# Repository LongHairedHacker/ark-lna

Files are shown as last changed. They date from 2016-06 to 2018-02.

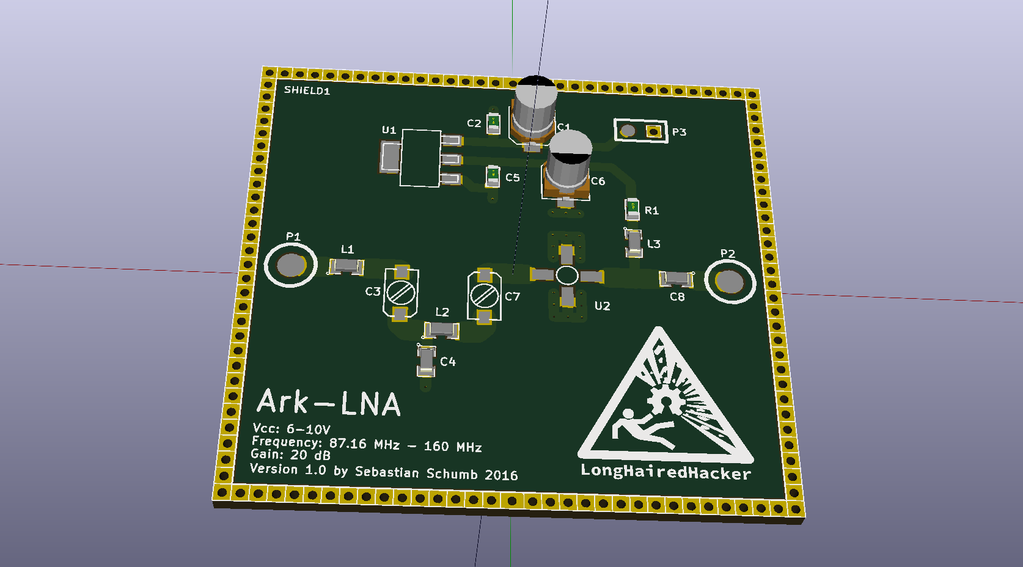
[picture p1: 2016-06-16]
plot/ark-lna.png

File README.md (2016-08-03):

ARK-LNA
=======
A low noise amplifier based on the MAR-6 or MAR-8.
It was designed with NOAA weather satellites in mind,
but might be useful for other VHF transmissions as well.

* Supply voltage: 6-10V
* Minimal center frequency: 87.16 MHz
* Maximal center frequency: 160 MHz
* Bandwidth: To be determined
* Gain: 20 dB

Parts
=====

| Count | Part				| Manufacturer Part	|
|---|---|---|
|  2 | Trimmer 3-10pf	| TZC3R100A110R00 	|
|  2 | Inductor 330nH	| MLF2012DR33JTD25	|
|  1 | 33pF 0805 | CL21C330JBANNNC |
|  1 | Inductor 10uH		| LBR2012T100K |
|  1 | 91 Ohm 0603 | RC0603JR-0791RL |
|  1 | 100pF 0805 | C0805C101J5GACTU  |
|  2 | 10uF | UUT1V100MCL1GS |
|  2 | 100nF 0603 | CL03A104KQ3NNNH |
|  1 | Voltage regulator | LM1117-5 |
|  1 | amplifier | MAR-6 / MAR-8 |
|  1 | case | TEKO 371 |

Notes
=====
* Case inner dimensions: 46.5mm x 50.5mm
* MAR-6+
    * Datasheet: http://194.75.38.69/pdfs/MAR-6+.pdf
    * Layout suggestions: https://www.minicircuits.com/pcb/98-pl262.pdf

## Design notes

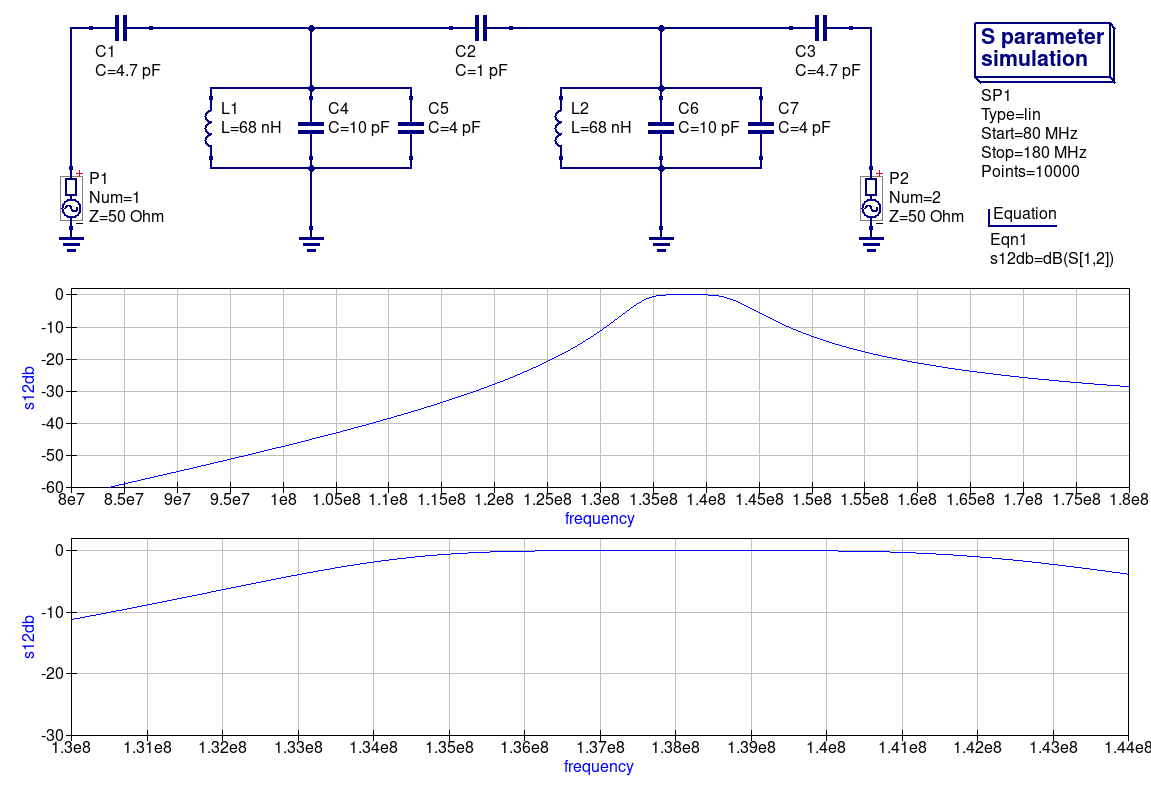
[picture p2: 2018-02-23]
plot/filter.png

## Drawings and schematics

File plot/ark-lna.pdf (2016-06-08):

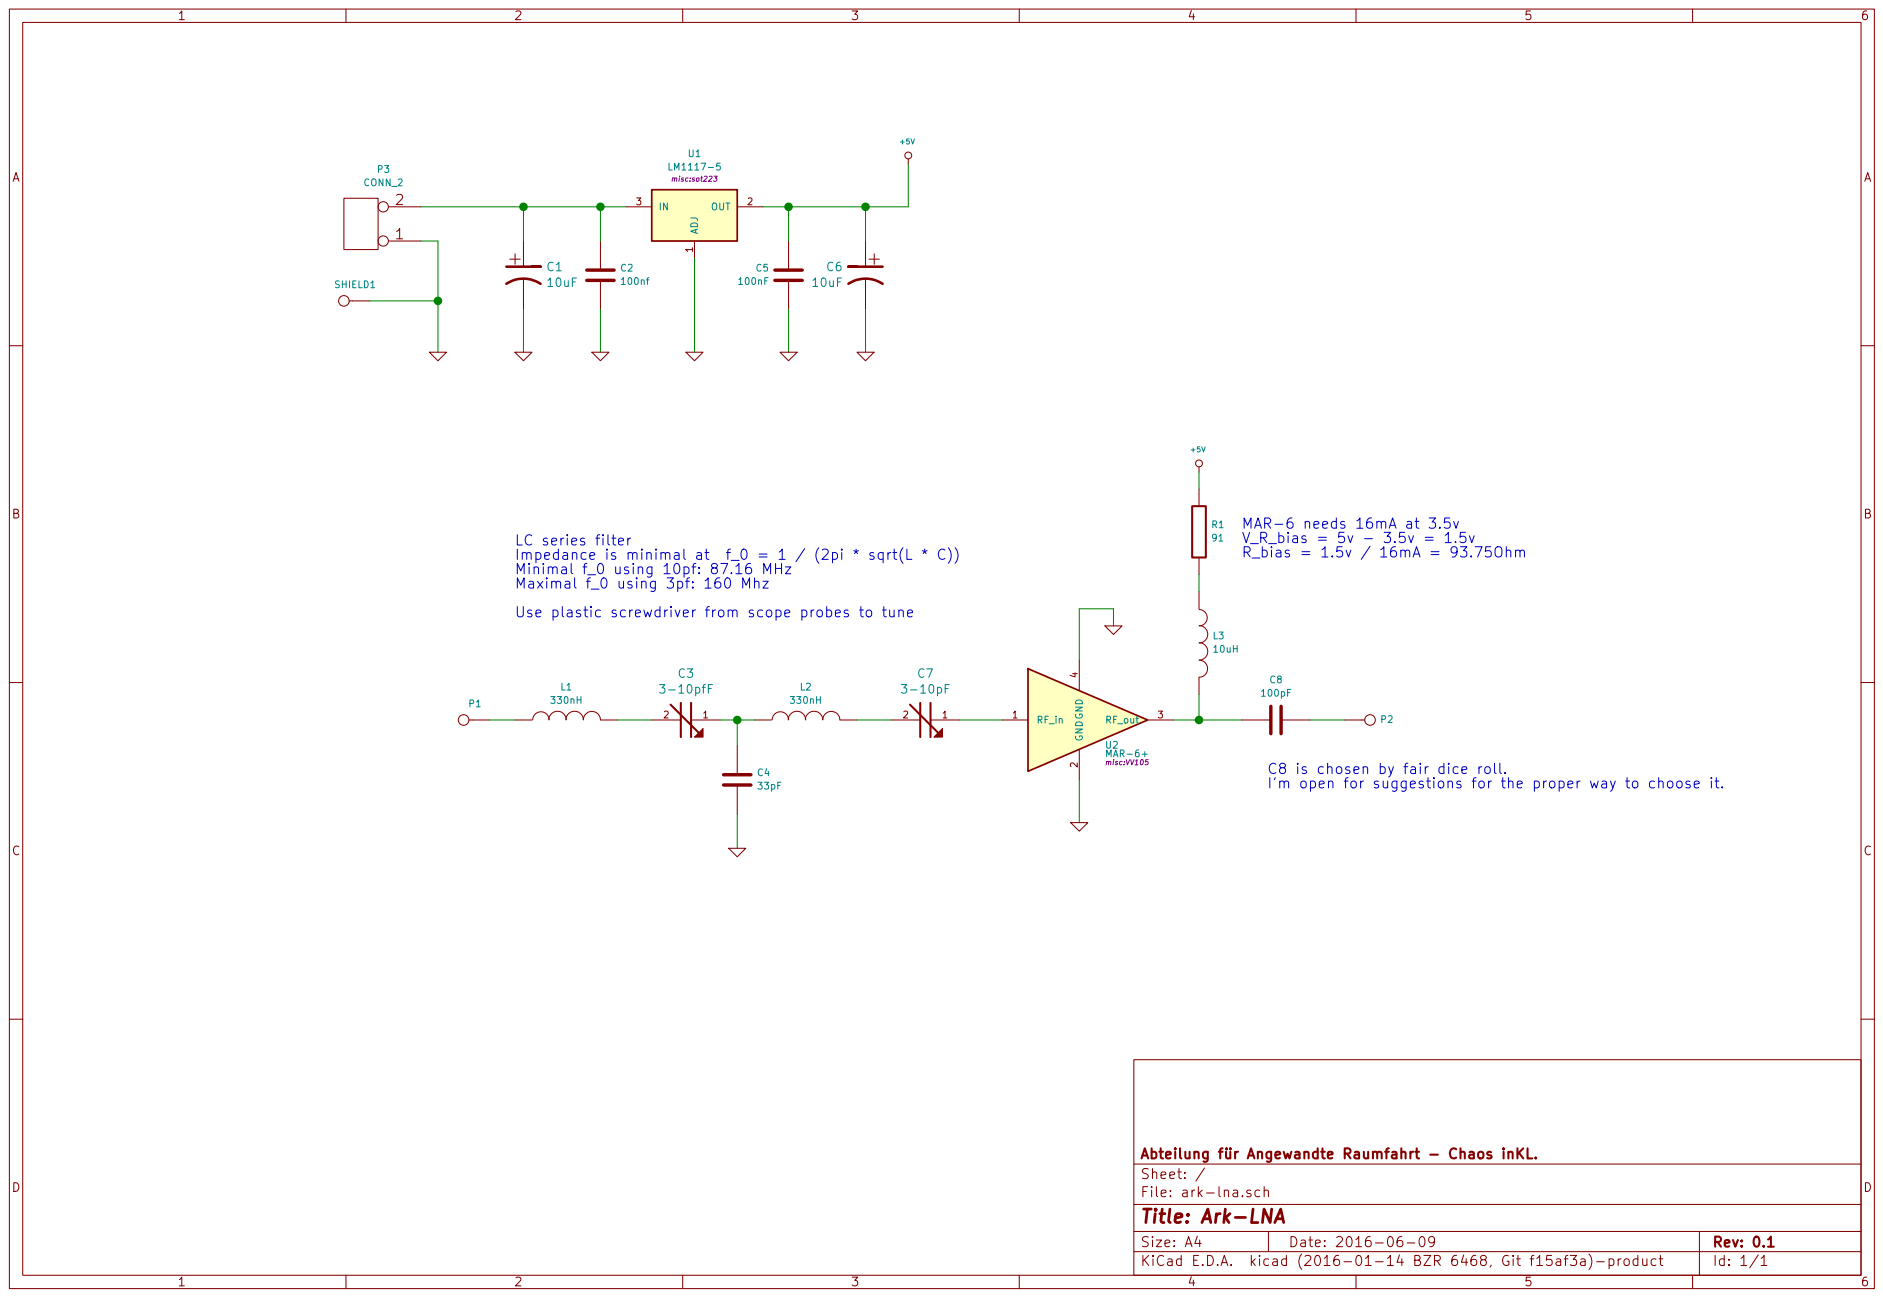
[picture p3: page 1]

I'm open for suggestions for the proper way to choose it. 1

100pF LC series filter
Impedance is minimal at f_0 = 1 / (2pi * sqrt(L * C))
Minimal f_0 using 10pf: 87.16 MHz
Maximal f_0 using 3pf: 160 Mhz

File: ark-lna.sch Sheet: / Abteilung für Angewandte Raumfahrt - Chaos inKL.

Id: 1/1 Title: Ark-LNA

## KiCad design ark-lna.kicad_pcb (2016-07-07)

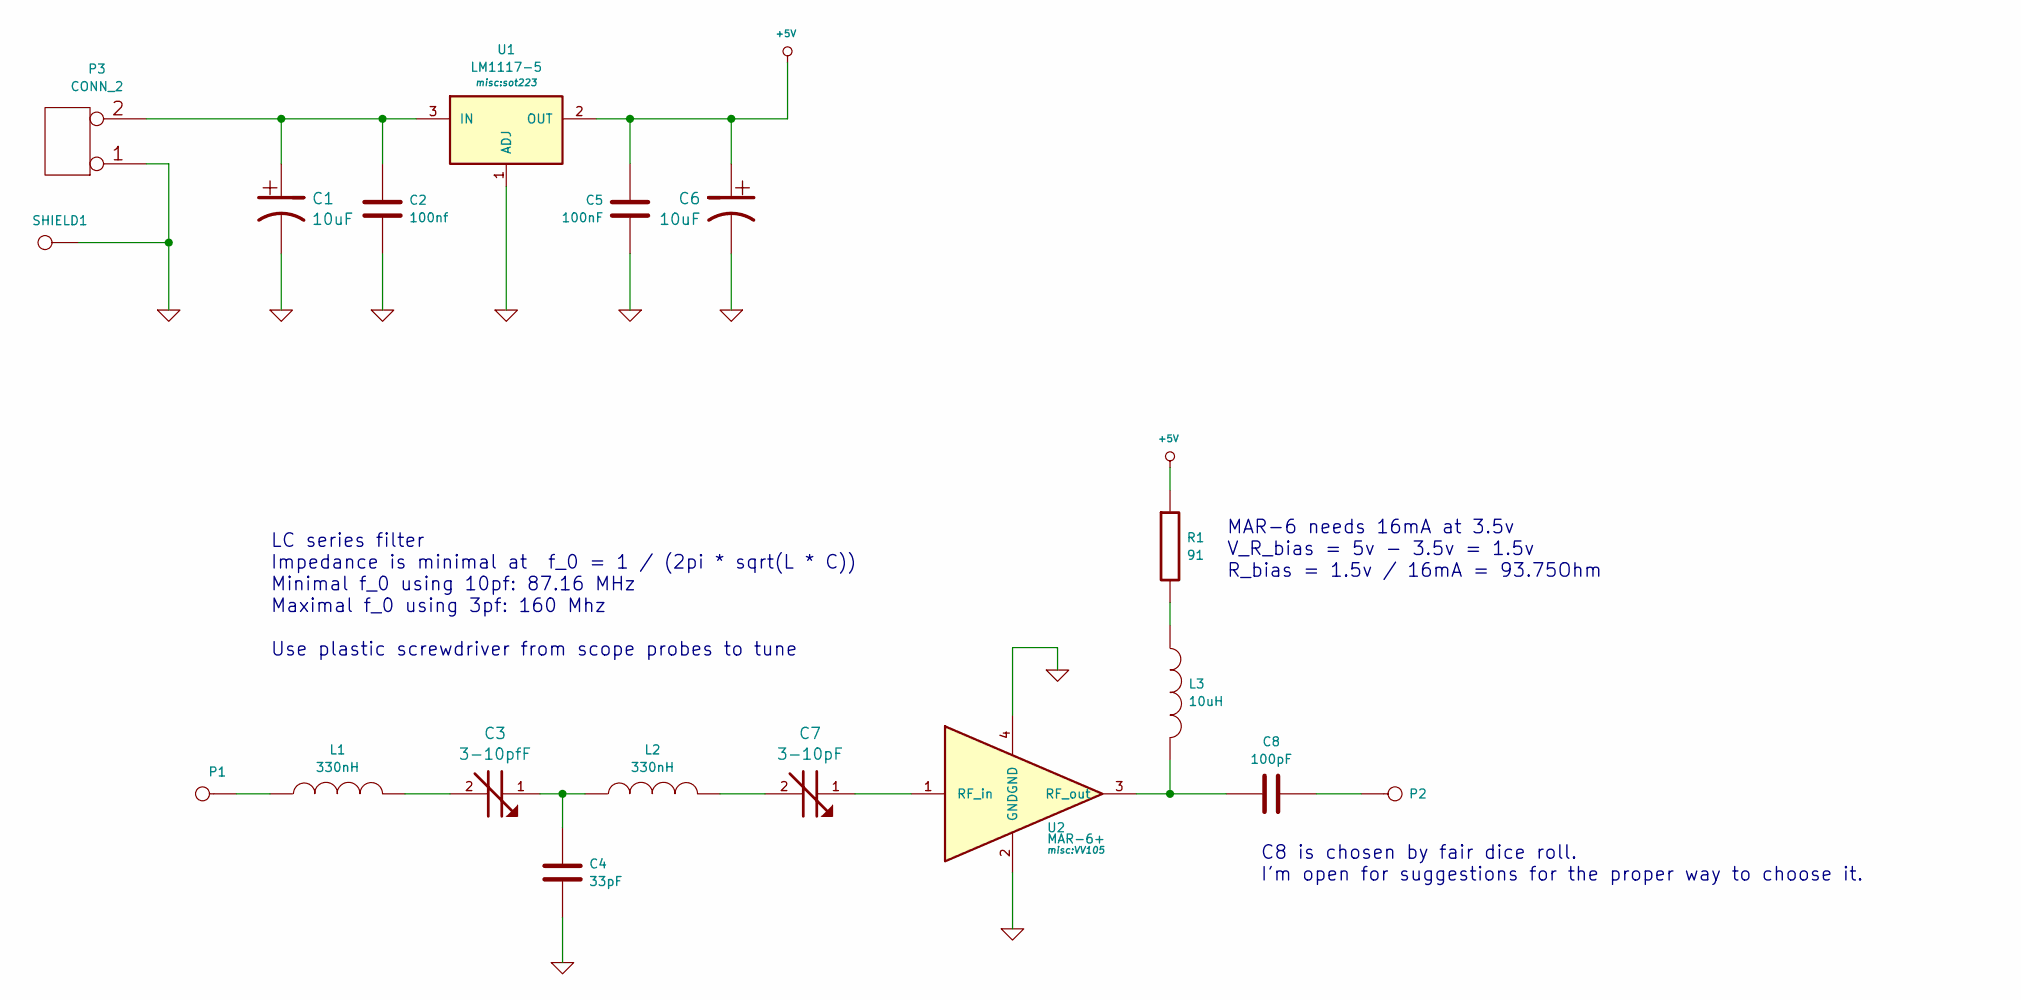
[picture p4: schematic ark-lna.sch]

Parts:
C1, C6: 10uF; c_elec_4x5.3
C2: 100nf; SM0603
C3: 3-10pfF; TZC3
C4: 33pF; SM0805
C5: 100nF; SM0603
C7: 3-10pF; TZC3
C8: 100pF; SM0805
L1, L2: 330nH; SM0805
L3: 10uH; SM0805
P1, P2: CONN_1; 1pin
P3: CONN_2; SIL-2
R1: 91; SM0603
SHIELD1: CONN_1; teko371
U1: LM1117-5; sot223
U2: MAR-6+; VV105

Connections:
+5V: C5.1, C6.1, R1.1, U1.2 (OUT)
GND: C1.2, C2.2, C4.2, C5.2, C6.2, P3.1, SHIELD1.1, U1.1 (ADJ), U2.2 (GND), U2.4 (GND)
unnamed: C1.1, C2.1, P3.2 (PM), U1.3 (IN)
unnamed: C3.1, C4.1, L2.1
unnamed: C3.2, L1.2
unnamed: C7.1, U2.1 (RF_in)
unnamed: C7.2, L2.2
unnamed: C8.1, P2.1
unnamed: C8.2, L3.2, U2.3 (RF_out)
unnamed: L1.1, P1.1
unnamed: L3.1, R1.2

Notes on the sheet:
MAR-6 needs 16mA at 3.5v V_R_bias = 5v - 3.5v = 1.5v R_bias = 1.5v / 16mA = 93.75Ohm
LC series filter Impedance is minimal at f_0 = 1 / (2pi * sqrt(L * C)) Minimal f_0 using 10pf: 87.16 MHz Maximal f_0 using 3pf: 160 Mhz Use plastic screwdriver from scope probes to tune
C8 is chosen by fair dice roll. I'm open for suggestions for the proper way to choose it.

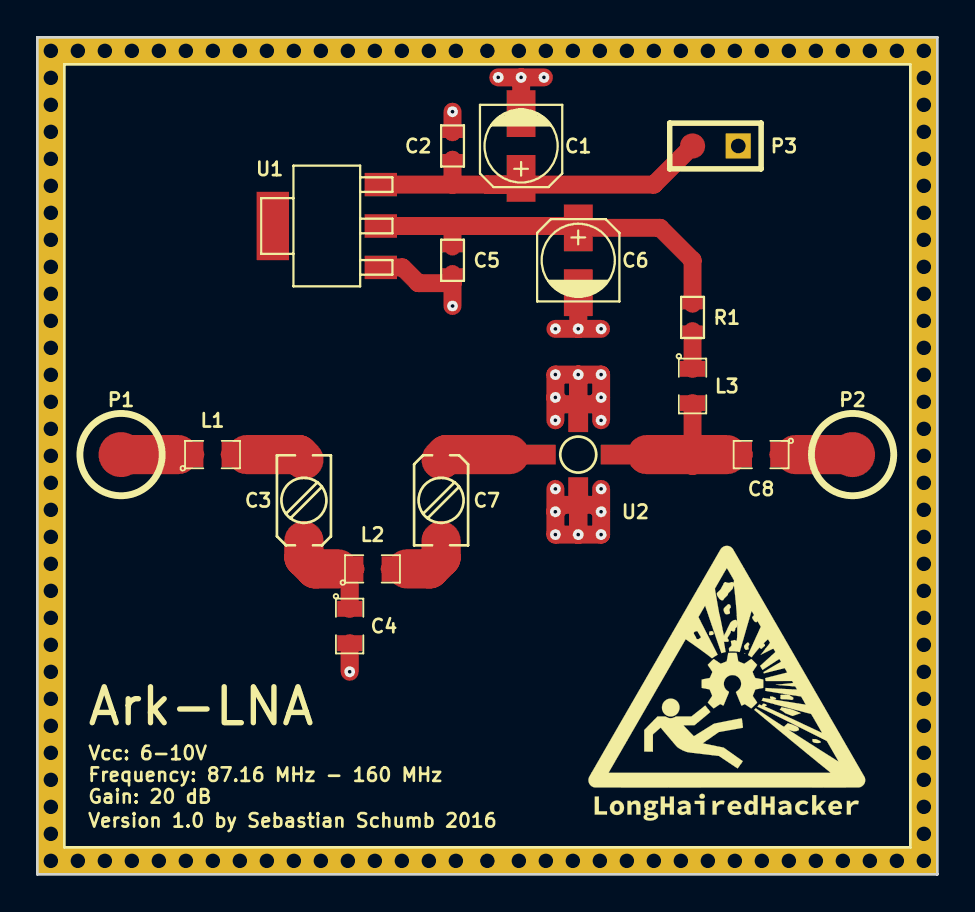
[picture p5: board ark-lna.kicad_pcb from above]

Board: 2 copper layers, 50.0 x 46.5 mm, 18 parts (0 on the bottom side), 11 nets.

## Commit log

2016-06-06 Added schematic
    [ark-lna.kicad_pcb, ark-lna.sch]
2016-06-08 Started assigning footprints
2016-06-08 Exchanged inductors for better availability Started layouting
    [ark-lna.kicad_pcb, ark-lna.sch]
2016-06-09 Reduce size to a 50mm x 50mm PCB
    [ark-lna.kicad_pcb]
2016-06-09 Minor cleanups
    [ark-lna.kicad_pcb]
2016-06-09 finishing touches on silkscreen
    [ark-lna.kicad_pcb]
2016-06-16 Fixed footprint for MAR-6
    [ark-lna.kicad_pcb]
2016-07-07 Final tweaks and gerber export
    [ark-lna-B.Cu.gbl, ark-lna-B.Mask.gbs, ark-lna-B.SilkS.gbo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]
2018-02-23 Added filter simulations
    [filter.sch, old_filter.sch]
